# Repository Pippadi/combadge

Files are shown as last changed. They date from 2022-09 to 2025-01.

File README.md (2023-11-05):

# combadge [Work in Progress]

A Star Trek combadge built with the ESP32-S3.

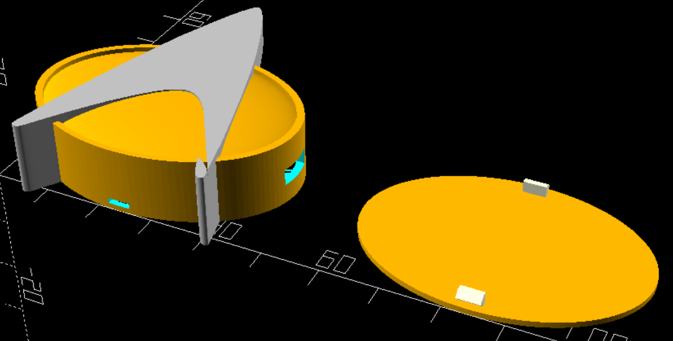
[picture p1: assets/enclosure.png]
Enclosure


> No copyright infringement is intended.
> This is simply a personal endeavor for fun and learning.

## Details

- Hardware and electronics: [hardware/pcb](hardware/pcb)
- Main ESP32 firmware: [software/combadge](software/combadge)
- Audio bridge: [software/bridge](software/bridge)
- 3D-printable enclosure: [hardware/enclosure](hardware/enclosure)
- Nuggets for testing: [software/test](software/test)
- Helpful scripts/tools: [software/tools](software/tools)

This is pretty much the entire directory tree. Happy exploring!

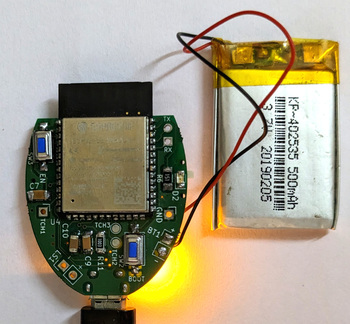
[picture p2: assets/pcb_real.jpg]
Assembled PCB
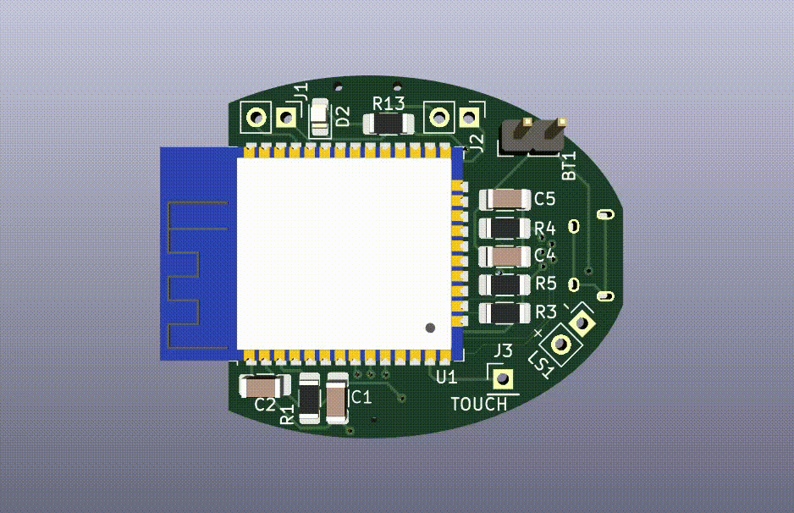
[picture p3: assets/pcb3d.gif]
PCB 3D View
 

## Goals

Hardware has now been verified to work.

Some kind of basic walkie-talkie functionality is in the works, built on top of a custom Combadge Real-time Audio Protocol.
[WebRTC](https://webrtc.org) or [Matrix](https://matrix.org) support is a goal for the distant future.

Ahead of this, the roadmap is largely undecided. Capable hardware leaves great scope for software.

## Motivations

This is a hobby project I am pursuing in order to broaden my knowledge and experience with embedded electronics and programming.
And of course, to end up with a combadge better than the ones they used on TV (I believe those are just molded and painted resin).
Please bear in mind that I am a beginner, especially when it comes to the electronics (remember that before you plug the batteries in).

## Community

Suggestions, tips, and contributions are welcome!
I hope that with some (of your?) time and effort, this combadge can grow to become more useful than a block of resin, while still retaining the charm.

All the tools used for this, as mentioned in the READMEs, are free and open-source. Thank you to those that made this possible!

See also [DansDesigns/ComBadge](https://github.com/DansDesigns/ComBadge), a project with a similar theme and very intriguing prospects.

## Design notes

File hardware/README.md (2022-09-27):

# Electronics and PCB

The combadge is built around an [ESP32-WROOM-32](https://www.espressif.com/en/support/documents/technical-documents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).
It is supposedly not recommended for new designs, but it's among the best supported by Arduino for programming, and it seems to be the only ESP32 variant that is cheaply available in my region.

## Sound

I've chosen to adopt I2S peripherals for this project, as they promise better audio quality than their analog counterparts, while reducing the amount of analog circuitry I have to design.
The [ESP32](https://docs.espressif.com/projects/esp-idf/en/v4.2.3/esp32/api-reference/peripherals/i2s.html) supports two I2S peripherals in hardware.

### Microphone

I've zeroed in on the [CMM-3526D-261-I2S-TR](https://www.cuidevices.com/product/audio/microphones/mems-microphones/cmm-3526d-261-i2s-tr).
I suppose any similar microphone will do the job. The manufacturer has very kindly provided [an official footprint](https://www.cuidevices.com/product/resource/pcbfootprint/cmm-3526d-261-i2s-tr).

### Speaker

With a speaker must come an amplifier. I chose the [NAU8315](https://www.nuvoton.com/export/resource-files/DS_NAU8315_DataSheet_EN_Rev1.7.pdf) because it's a class D amplifier that takes I2S input, and can drive a speaker with pretty much no external circuitry.

As an exercise, I designed the PCB footprint for the NAU8315.

I'm still on the lookout for an actual speaker.

## Power Management

The unit runs on a lithium-polymer battery. Exact model and size unknown as of now. I'm expecting it to be one of the usual 3.7V LiPo cells.
At this stage, though, I'm more concerned with battery management.

All the chosen components of the combadge operate on 3.3V. I was hoping to find an all-in-one charging and voltage-regulating IC, but none seem to exist for these parameters.
For charging, I plan to use an [XC6808A4D28R-G](https://www.torexsemi.com/products/battery-charge-ics/series/?name=xc6808) and a zener diode circuit for over-discharge protection.
I found the super tiny 250mA [NCP160](https://www.onsemi.com/products/power-management/linear-regulators-ldo/ncp160) LDO linear regulator for 3.3V power.

I still need to verify whether 250mA is enough for the entire combadge (it better be; it's running off a battery).
I'm hoping decoupling capacitors will take care of any current spikes the ESP32 and speakers may need.

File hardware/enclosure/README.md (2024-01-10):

# Enclosure

The 3D-printable combadge enclosure for the electronics to sit inside. 3D design is done in [OpenSCAD](https://openscad.org/).

I couldn't find any official combadge dimensions online, so I based my dimensions off of numbers given in this [forum thread](https://www.therpf.com/forums/threads/dimensions-of-star-trek-communicator-badge.266118/).

The PCB is a `45mm x 31mm` ellipse with some parts lopped off where required.
The enclosure's ellipse is `47.5mm x 33.5mm`. Walls are `1mm` thick, with a `0.5mm` room for error around the edge of the cavity for the electronics.

The chevron [SVG](chevron.svg) was traced with Inkscape from a bitmap.

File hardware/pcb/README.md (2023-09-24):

# Electronics and PCB

See the [assets](assets) directory for screenshots of the schematics and PCB.

## Component Choices

The combadge is built around an [ESP32-S3-WROOM-1](https://www.espressif.com/en/support/download/documents/modules?keys=&field_type_tid%5B%5D=838).

I chose it because:

- It has hardware I2S and touch support
- It is well-supported by the Arduino toolchain
- It is cheaply available in my region

### Sound

I've chosen to adopt I2S peripherals for this project, as they promise better audio quality than their analog counterparts, while reducing the amount of analog circuitry I have to design.
The [ESP32-S3](https://docs.espressif.com/projects/esp-idf/en/latest/esp32s3/api-reference/peripherals/i2s.html) supports two I2S peripherals in hardware.

#### Microphone

I've zeroed in on the [Knowles SPH0645LM4H-1](https://www.knowles.com/docs/default-source/default-document-library/sph0645lm4h-1-datasheet.pdf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).
Any similar microphone ought to do the job.

I use the INMP441 for prototyping because it's available as a module. I would have stuck with it for the PCB, but it seems to be discontinued by the manufacturer.

#### Speaker

The [Taoglas SPKM.10.8.A](https://www.taoglas.com/product/10-mm-round-miniature-speaker-500mw/) seems like an adequate speaker for the job.

A [MAX98357AETE+T](https://www.analog.com/en/products/max98357a.html#product-overview) class D amplifier drives the speaker.
It's what I use to prototype.

### Power Management

The unit runs on a lithium-polymer battery. Exact model and size undecided as of now. It will be one of the usual 3.7V LiPo cells.
All the chosen components of the combadge operate on 3.3V. I was hoping to find an all-in-one charging and voltage-regulating IC, but my searches yielded none for these parameters.

Charging is handled by an [MCP73831](https://www.microchip.com/en-us/product/MCP73831).
A 300mA [TLV74333PDBVR](https://www.ti.com/product/TLV743P/part-details/TLV74333PDBVR) LDO linear regulator provides 3.3V power.
A [TLV431AQFTA](https://www.diodes.com/assets/Datasheets/TLV431Q.pdf)-based circuit conditionally disables the regulator for battery over-discharge protection.

## PCB

The PCB has been designed in KiCAD.

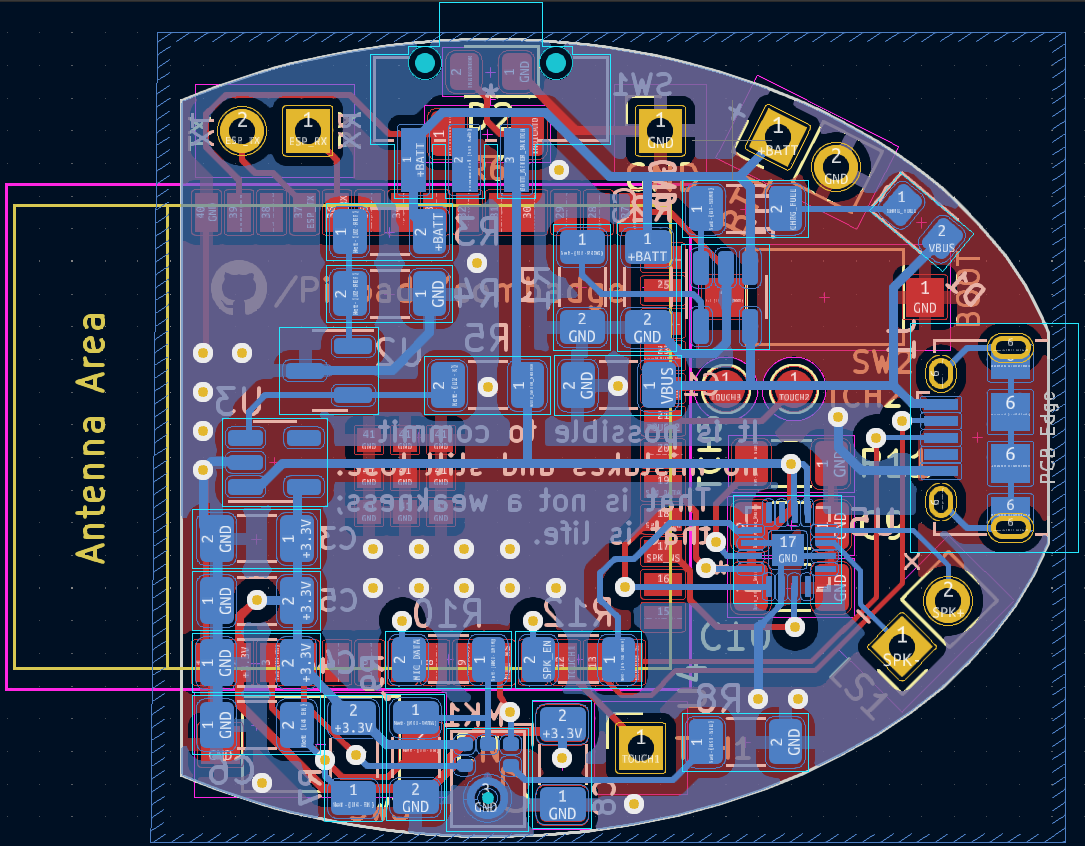
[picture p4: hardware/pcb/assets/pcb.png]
PCB


- Footprints are chosen to be as large as possible where applicable, to facilitate hand-soldering or rework.
- The PCB has headers to which battery and speaker wires can be soldered.
- Certain measurements can be seen in the `User.Comments` layer.

This project makes use of the official Espressif [ESP32 KiCAD libraries](https://github.com/espressif/kicad-libraries).

You will need to change the paths to the third party symbols in the library and footprint managers. I've just plonked everything in a gitignored folder called `third-party`.

## Notes

### Crackling on speaker

When I was prototyping, I was powering everything off my computer's USB port. The INMP441 microphone module worked well, but the MAX98357 with no power supply filtering was horribly noisy.
Some beefy electrolytic capacitors reduced the noise, but did not eliminate it.

The root cause of the noise turned out to be the fact that I was powering the speaker through the AMS1117 3.3V regulator on my ESP32 dev board.
The regulator could not handle the current spikes demanded by the speaker, so its output voltage ended up dropping.
Hooking the speaker up directly to the USB 5V line (VIN on my particular dev board) solved the issue.

The PCB has been designed such that the amplifier is powered directly by the battery.
There are also some large low-transient-response-time ceramic capacitors for any bursts of energy components may need.

### SPH0645LM4H woes

The SPH0645 is known to have some quirks in its I2S interface, to do with the synchronization of the clock and data signals.
In addition, the signal it outputs has a weird offset from 0.

The required workaround for the first problem has been successfully implemented and the second is more of an annoyance.
Nevertheless, a future board revision may be better off with a more standard-compliant microphone like the ICS43434.

### Power stability during battery-less operation

The MCP73831 datasheet specifies a minimum value of 4.7uF for a capacitor across the battery side (C2 here) for stable supply when the battery is disconnected.
This is enough for the ESP32-S3 to boot, but not enough for more current-demanding tasks like turning on WiFi.
Future board revisions should have more and bigger capacitors to avoid brownouts when testing without a battery.

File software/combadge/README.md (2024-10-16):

# combadge

The code for the actual combadge, written in C++ for use with [Arduino](https://www.arduino.cc/), and of course the [ESP32 toolchain](https://github.com/espressif/arduino-esp32).
While the current hardware uses the ESP32-S3, the code aims to retain support for the ESP32.

## Usage

- Edit `config.h` to match your hardware and software configurations.
    + The default pins and peripherals correspond to the hardware in this repository. Change accordingly if using something different.
    + WiFi credentials and bridge host and port will need to be changed per your setup.
    + At present, all involved parties will need to have the same audio configuration. So, changing items such as `sample_t` or `SAMPLE_RATE` will require similar changes to the bridge and the other clients/combadges.
- Run `make SOC="esp32s3"` and `make flash PORT="/dev/<your port>"`. `SOC` can be set to `esp32` if required.

## Dependencies

- [Arduino CLI](https://arduino.github.io/arduino-cli/0.36/) (when building with Makefile)
- WiFi (See [`WiFiClient.h`](https://github.com/espressif/arduino-esp32/blob/master/libraries/WiFi/src/WiFiClient.h))
- I2S (See [`i2s.h`](https://github.com/espressif/arduino-esp32/blob/master/tools/sdk/esp32/include/driver/include/driver/i2s.h) and [`hal/i2s_types.h`](https://github.com/espressif/arduino-esp32/blob/master/tools/sdk/esp32/include/hal/include/hal/i2s_types.h))

## Outline

At startup, two threads are started - one for transmitting microphone data and another for receiving and playing back speaker data.

All data is sent with the Combadge Real-time Audio Protocol (CRAP).

The intricacies of I2S communication are abstracted out to classes, specially defined for each hardware peripheral.
The underlying plan is to eventually define a speaker and microphone interface, and write uniform implementations for specific microphone and speaker peripherals to make switching hardware simpler.

Configurations, constants, and other definitions can be found in [`config.h`](config.h).

## Combadge Real-time Audio Protocol

[CRAP](src/crap.h) is a standard for sending audio data and transmission-related events.

### Topology

A central bridge handles all communication to an from an individual client (badge).
Clients are aware only of the existence of the bridge.
The bridge has the responsibility of routing audio data between clients, and sending the appropriate ephemeral events when necessary.

### Communication

CRAP uses TCP as the underlying communication protocol. A client connects to a bridge on startup, and keeps the connection open.
The client is considered to be offline when the socket is closed.

Information is sent in CRAP packets. A packet mandatorily has a header, and may have a body.
The `PacketHeader` has the following structure.

```c
typedef struct {
    uint32_t type;
    uint32_t size;
} PacketHeader;
```

`type` holds an enumerated intent of the message. `size` holds the size in bytes of the rest of the message body.
Currently, three packet `type`s have been defined.
These three messages are used both by badges and the bridge to start and stop transmissions.

- `AUDIO_START`: Starts an audio transmission. `size` is 0 as no further body is necessary.
- `AUDIO_STOP`: Ends an audio transmission. `size` is 0 as no further body is necessary.
- `AUDIO_DATA`: Holds audio samples in the agreed-upon format (currently raw signed 16-bit little-endian). `size` is the number of samples read times the configured `BYTES_PER_SAMPLE`.

Right now, configurations like sample rate and bitness are hardcoded (but modifiable in `config.h`) for the sake of simplicity.
Allowing on-the-fly setting of such parameters is a goal for the future.
It is currently assumed that both the bridge and clients have been appropriately configured to use the same audio format.

For more information on the bridge, see [/software/bridge](/software/bridge).

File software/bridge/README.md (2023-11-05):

# combridge

A bridge which aggregates and routes audio streams from multiple badges/clients, implementing the [Combadge Real-time Audio Protocol](/software/combadge).

Audio transmissions from clients are aggregated by the bridge such that each client receives a single audio stream to play back.

For now, the aggregated stream for a client is the sample-by-sample sum of the streams from other clients.
In time, streams will be converted to frequency domain and aggregated that way. This makes handling of streams with different sample rates and packet sizes easier.
Acoustic echo cancellation, active noice cancellation, and automatic gain control are also on the list of things to implement.

In its current state, the bridge is very rudimentary, kludgy, and buggy.

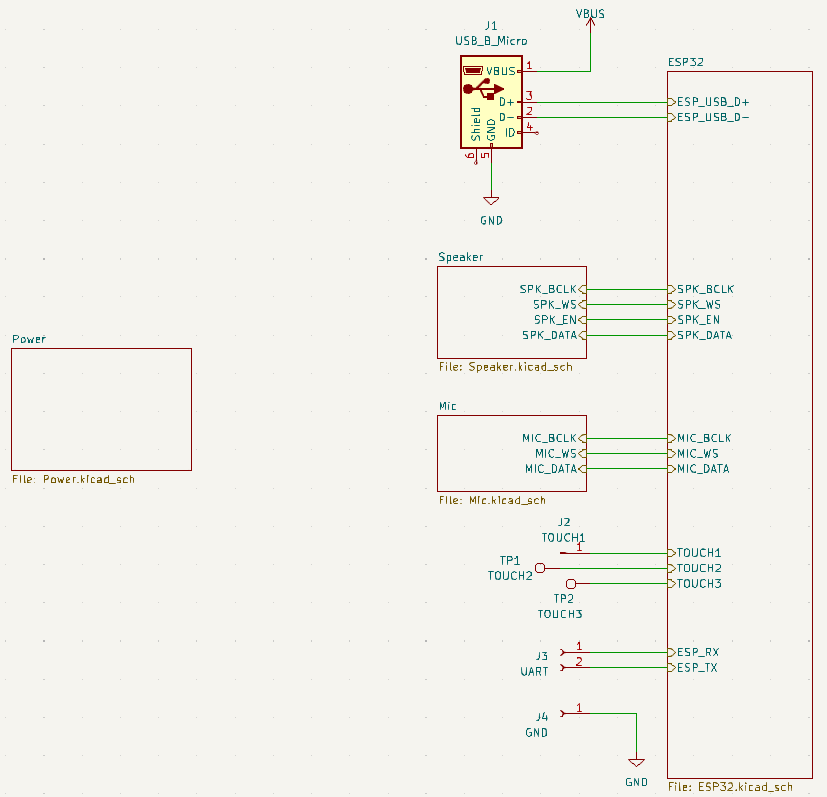
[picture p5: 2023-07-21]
hardware/pcb/assets/TopLevelSchematic.png

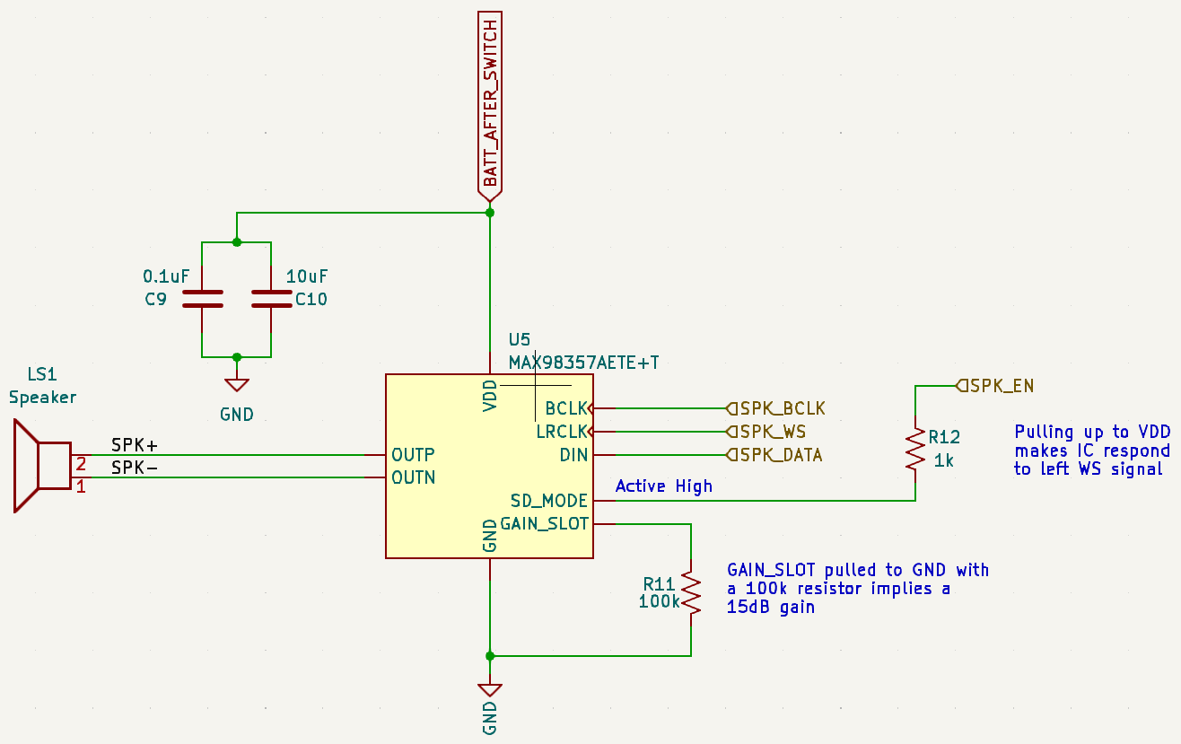
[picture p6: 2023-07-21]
hardware/pcb/assets/SpeakerSchematic.png

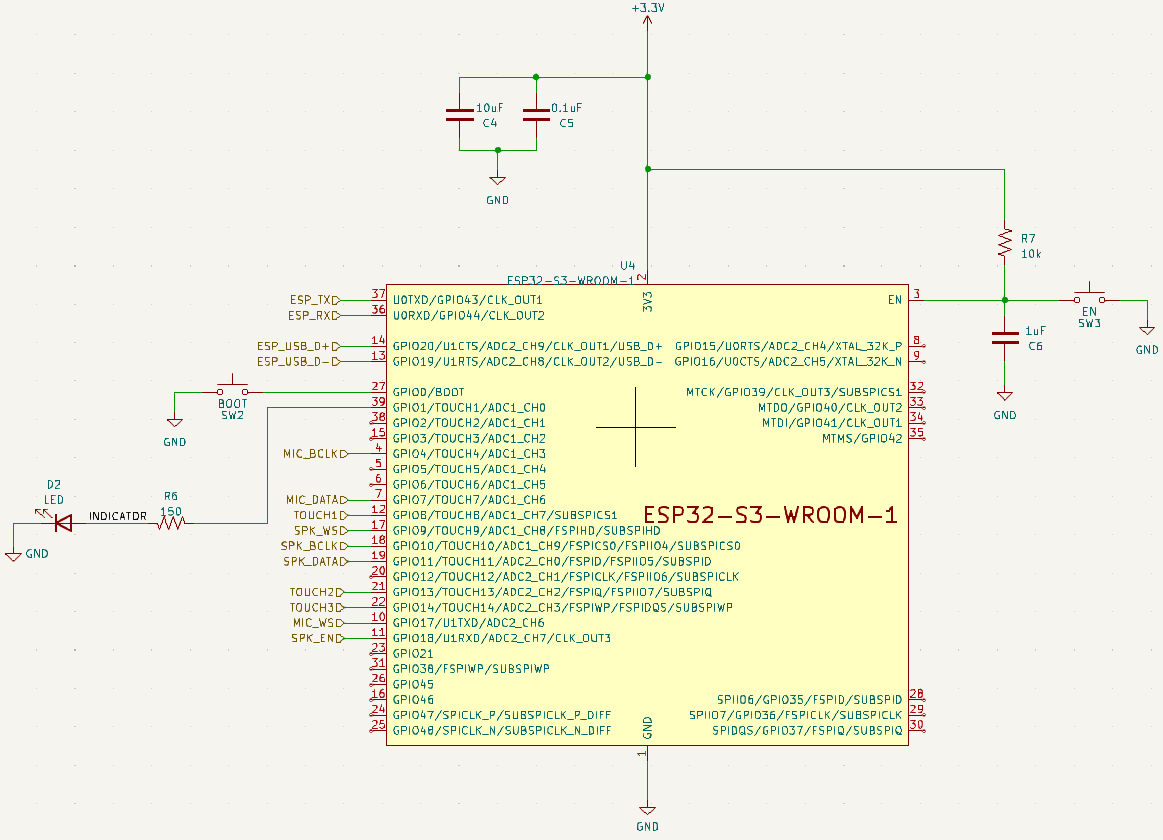
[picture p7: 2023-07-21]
hardware/pcb/assets/ESP32Schematic.png

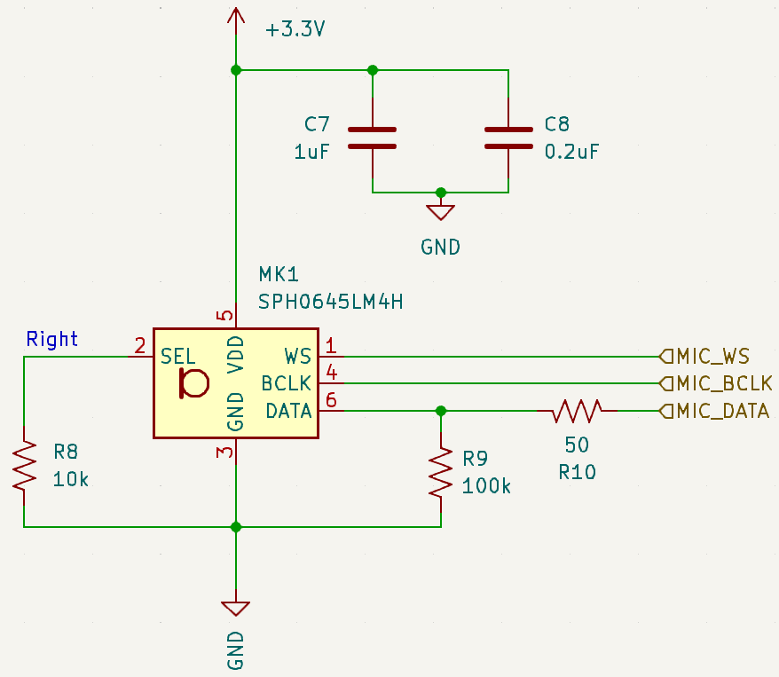
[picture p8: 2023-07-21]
hardware/pcb/assets/MicrophoneSchematic.png

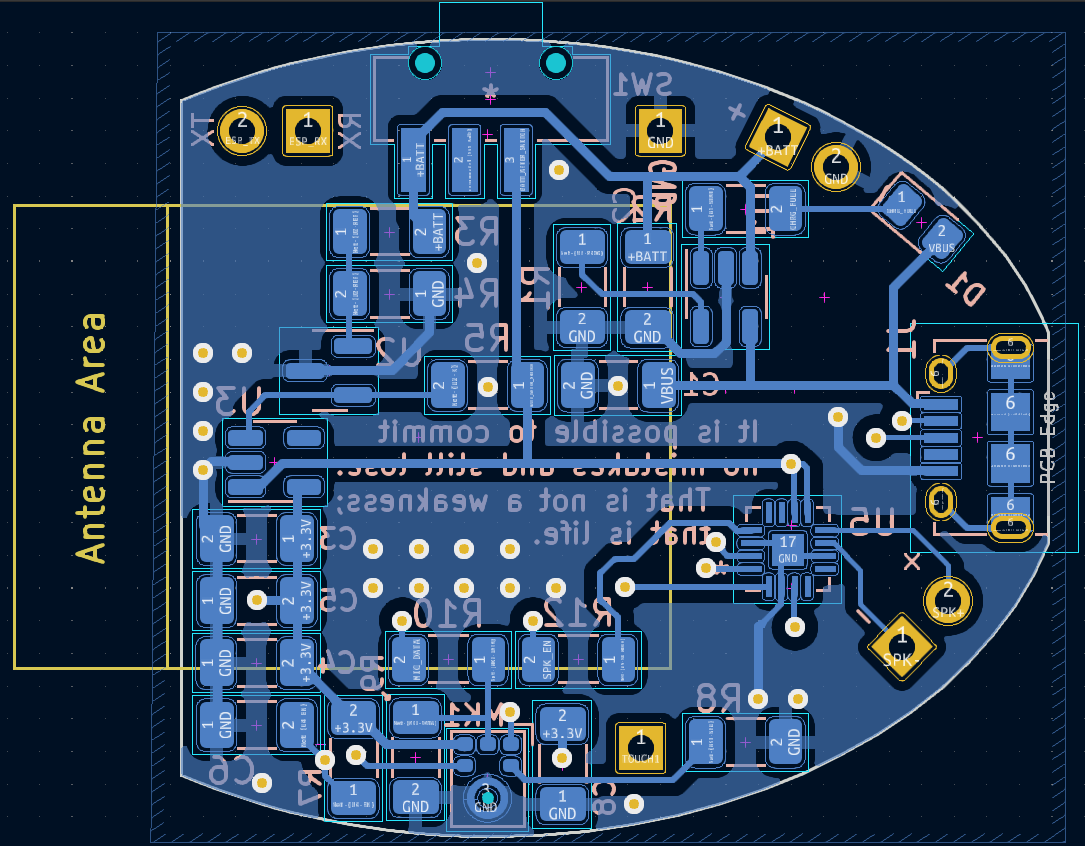
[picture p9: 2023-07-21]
hardware/pcb/assets/PCBRear.png

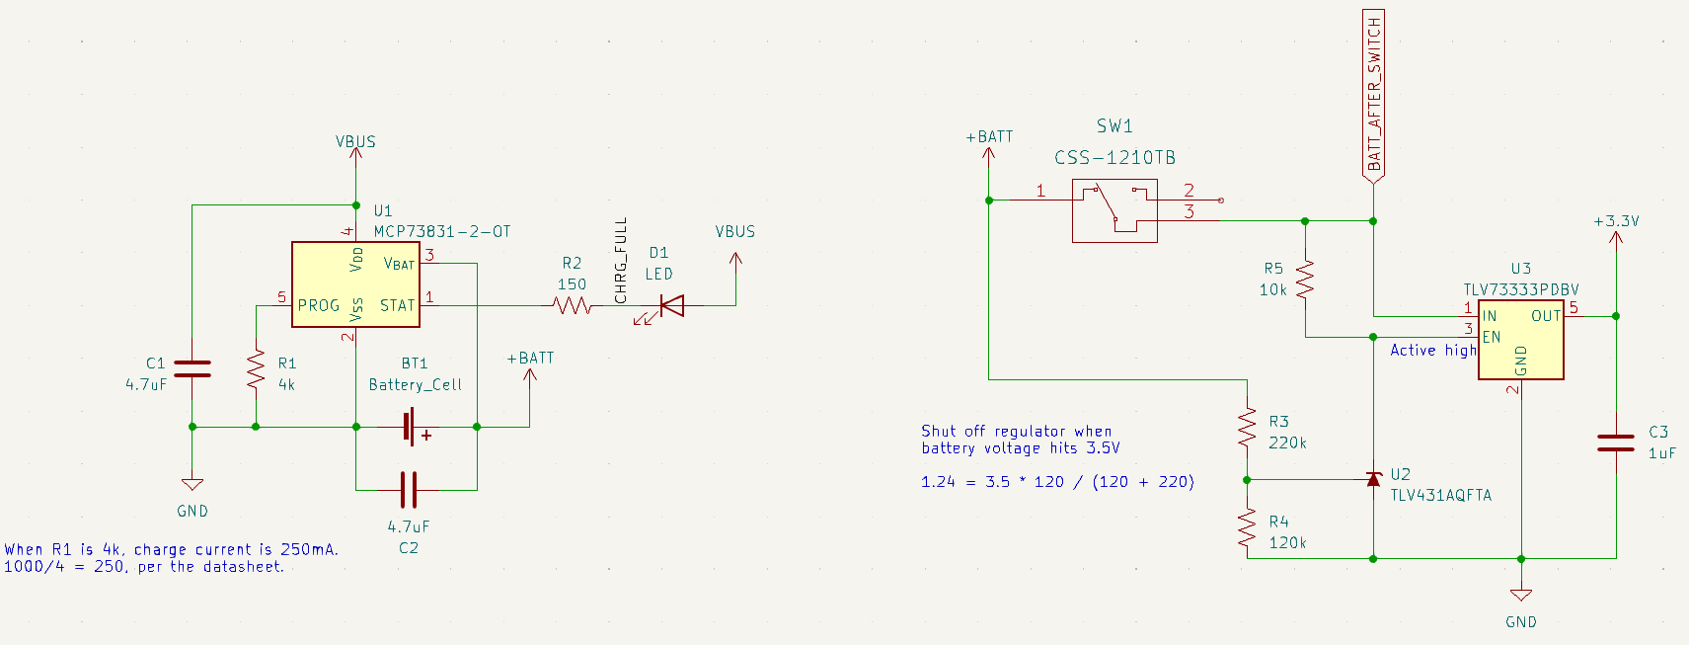
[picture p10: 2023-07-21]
hardware/pcb/assets/PowerManagementSchematic.png

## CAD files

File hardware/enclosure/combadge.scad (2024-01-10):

$wallThickness = 1;
$wiggleRoom = 0.5;
$chamberDepth = 10;

$pcbMajorAxis = 45;
$pcbMinorAxis = 31;

$chevronHeight = 13;

$chamberLength = $pcbMajorAxis + 2*$wiggleRoom;
$chamberWidth = $pcbMinorAxis + 2*$wiggleRoom;
$baseLength = $chamberLength + 2*$wallThickness;
$baseWidth = $chamberWidth + 2*$wallThickness;

$clipWidth = 4;
$clipHeight = 2;

$fn=128;

module scale_width() {
    translate([$baseLength/2, $baseWidth/2, 0])
        scale([$baseLength/$baseWidth, 1, 1])
        children();
}

module chevron() {
    difference() {
        linear_extrude($chevronHeight) import("chevron.svg");
        translate([10, 40, 0]) cube([30, 30, 8]);
    }
}

module annulus(outer_radius, width, height) {
    linear_extrude(height) difference() {
        circle(outer_radius);
        circle(outer_radius - width);
    }
}

module base_top() {
    scale([1, 1, 5.5/$baseWidth])
        rotate_extrude() 
        intersection() {
           circle($baseWidth/2);
           square([$baseWidth, $baseWidth], center=false);
        }
    annulus($baseWidth/2, 1, 1.75);
}

module base() {
    scale_width()
    union() {
        cylinder($chamberDepth, d = $baseWidth);
        translate([0, 0, $chamberDepth]) base_top();
    }
}

module cavity_with_holes() {
    scale_width() cylinder($chamberDepth, d = $chamberWidth);
    translate([$baseLength/2, $baseWidth/2, $chamberDepth/2]) {
        translate([0, $baseWidth/2, 1]) cube([5, 5, 3], center=true);
        translate([$baseLength/2, 0, 0]) cube([5, 7, 3], center=true);
    }
    translate([$baseLength/2, 0, 0.5+$clipHeight/2]) {
        cube([$clipWidth, 5, 1], center=true);
        translate([0, $baseWidth, 0]) cube([$clipWidth, 5, 1], center=true);
    }
}

module combadge() {
    difference() {
        union() {
            color("#c0c0c0") translate([6, -2, 0]) scale([0.85, 0.85, 1]) chevron();
            color("#ffb700") base();
        }
        cavity_with_holes();
    }
}

module triangularPrism(side, depth, center=false) {
    linear_extrude(depth) polygon([[0, 0], [side, 0], [side/2, sqrt(3)*side/2]]);
}

module snapClip(height, width, center) {
    translate(center==true ? [-1, -width/2, 0] : [0, 0, 0])
    union() {
        translate([0, 0, height]) rotate([-90, 0, 0])
        linear_extrude(width)
        polygon([[0, 0], [1 ,0], [2, 1], [1, 1], [1, height], [0, height]]);
    }
}

module back() {
    translate([$baseLength/2, 0, $wallThickness]) union() {
        translate([0, 0.5+$wallThickness, 0]) rotate([0, 0, -90])
        snapClip($clipHeight, $clipWidth, true);
        translate([0, $baseWidth-(0.5+$wallThickness), 0]) rotate([0, 0, 90])
        snapClip($clipHeight, $clipWidth, true);
    }
    scale_width() color("#ffb700")
    cylinder($wallThickness, d=$baseWidth, center=false);
}

combadge();
translate([60, 0, 0])
back();

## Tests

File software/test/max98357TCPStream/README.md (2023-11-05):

# max98357TCPStream

A test for streaming audio data over TCP to the MAX98357.

Set WiFi credentials and I2S configurations as necessary in `max98357TCPStream.ino`.
Configure `streamSound.py` to use the corresponding settings as well.

Next, use `ffmpeg` to convert a given audio file to the required raw format. Change settings if necessary.

```sh
ffmpeg -y -i YourSound.mp3 -f s16le -ac 1 -ar 44100 YourSound.raw
```

Finally, upload the code to the ESP32, and invoke the python script.

```sh
python3 streamSound.py YourSound.raw
```

Audio playback should be fairly smooth. If you have noise, it is very likely to be on the power supply line.
Probing with an oscilloscope may be useful to diagnose issues. See [hardware/pcb](/hardware/pcb#crackling-on-speaker) for more insight.

To make sure it's not your testing scripts that are at fault, use `streamSound.py` in conjunction with [/software/test/inmp441TCPStream/tcpRecorder.py](/software/test/inmp441TCPStream/tcpRecorder.py) to make sure that the sound you put in is the same sound you get out.

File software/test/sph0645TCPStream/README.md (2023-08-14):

# sph0645TCPStream

A test program which streams recording microphone data points over TCP for a Python program to persist to file

## Usage

1. Modify `sph0645TCPStream.ino` to set constants like pins and WiFi credentials commensurate with your setup.
2. Open port 1592 on your firewall, and run `tcpRecorder.py`.
3. Upload the sketch to your ESP32.
4. Let the setup run while making test noises.
5. Terminate the Python program with Ctrl-C.
6. Launch Audacity, and use `File -> Import -> Raw Data` to import your data as 44100Hz signed 16-bit little-endian (should be default).

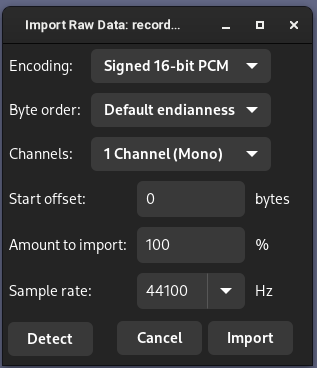
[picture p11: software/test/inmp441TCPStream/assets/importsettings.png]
Audacity import settings


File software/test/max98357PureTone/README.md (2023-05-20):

# MAX98357 Pure Tone test

The ESP32 generates a pure tone and sends it over I2S to the MAX98357.

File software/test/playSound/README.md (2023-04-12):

# playSound

A test to verify whether audio clip playback works with the MAX98357.

The sound clip header file was generated with [tools/soundClips](/software/tools/soundClips).
So far, I've had good results with 44100Hz sample rates for both the audio clip and the amplifier.

16000Hz playback works with the amplifier, but I just can't get a sound clip to play at that sample rate, and I don't know why.
I still need to test other sample rates (and verify that my process isn't at fault) to see where exactly it stops working.

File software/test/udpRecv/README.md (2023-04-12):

# UDP reception test

This is a simple set of programs for testing testing UDP reception.
The python program sends packets with the same content (no PRBS or anything right now {Yes, I just learned what a PRBS was}).
The ESP prints the number of bytes read and the first character in the bytestream.

Yeah, this needs to be improved.

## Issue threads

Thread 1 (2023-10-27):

Great Progress!

DansDesigns, 2023-10-27:
Hi Pippadi,

Loving the progress youve made!
I see you have moved over to the new ESP32 chips.. have you tested the built-in speech recognition functions yet?

Have you considered putting a video together showing the current working state or the Badge?

Keep up the good work!

Pippadi, 2023-11-01:
Thank you!

No, not yet! I was under the impression earlier that I needed a separate DSP chip or something for the speech recognition to work, but some more reading tells me that I don't. Thanks for the reminder!

College and stuff has been keeping me busy lately, so I haven't been able to give this project as much attention as I want to. I'm trying to get some kind of real-time multi-badge audio streaming working with a central bridge. Perhaps that should be my milestone for the first video.

I've been meaning to learn a little bit about audio signal processing, so that I can implement some basic echo and noise cancellation. Again, I haven't found the time, and these don't look like the kind of topics that can be covered in a week or two :)

Pippadi, 2024-03-09:
Enabled the Discussions feature. Closing.

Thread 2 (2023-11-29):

Feature Request: Touch Sensor Input(s)

cinderblock, 2023-11-29:
Awesome work!

I see that the ESP32-S3 has a Touch controller. Have you considered bringing a couple GPIO out that have touch support? Could make for awesome touch buttons!

Pippadi, 2023-11-30:
Thank you!
The current iteration of the hardware does in fact have three touch-capable GPIOs broken out (see [schematic](https://github.com/Pippadi/combadge/blob/main/hardware/pcb/assets/TopLevelSchematic.png)).

`TCH1` is intended to be connected to the chevron and act as the main button. `TCH2` and `TCH3` were admittedly added as afterthoughts, and are just broken out to some test points because I was out of board space :)

At present, the software makes use of only `TCH1`, but I'm sure some use will be found for the other two.

cinderblock, 2023-11-30:
Oh dam! I didn't see a schematic print so I couldn't investigate fully without starting up the full KiCad and was going off of, what may be old, renderings.

Carry on :)

Closed 2023-11-30.

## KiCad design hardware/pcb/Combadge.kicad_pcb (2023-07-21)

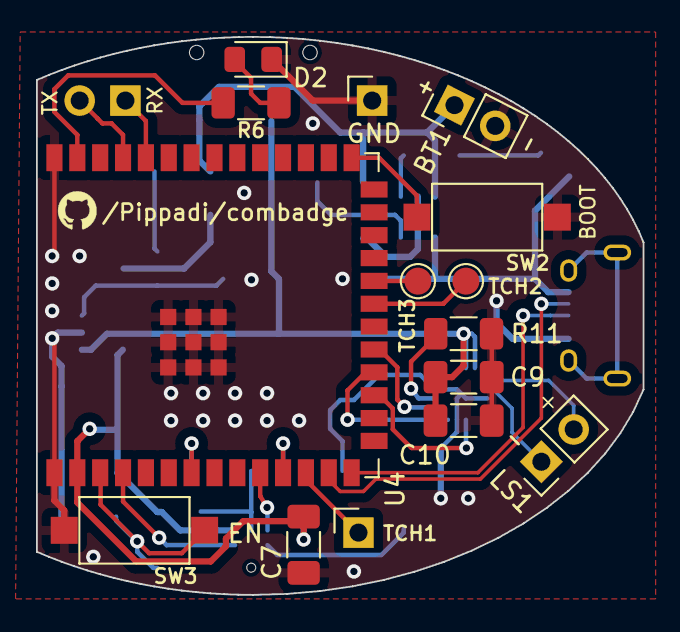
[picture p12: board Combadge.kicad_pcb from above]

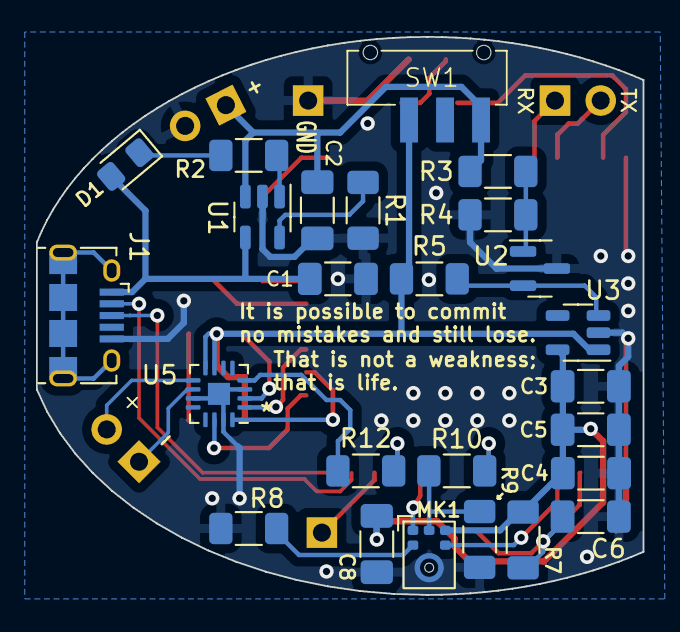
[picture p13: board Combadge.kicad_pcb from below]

Board: 2 copper layers, 33.7 x 31.0 mm, 41 parts (25 on the bottom side), 34 nets.

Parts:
BT1: Battery_Cell; PinHeader_1x02_P2.54mm_Vertical
C1, C2: 4.7uF; C_1206_3216Metric_Pad1.33x1.80mm_HandSolder
C3, C6, C7: 1uF; C_1206_3216Metric_Pad1.33x1.80mm_HandSolder
C4, C10: 10uF; C_1206_3216Metric_Pad1.33x1.80mm_HandSolder
C5, C9: 0.1uF; C_1206_3216Metric_Pad1.33x1.80mm_HandSolder
C8: 0.2uF; C_1206_3216Metric_Pad1.33x1.80mm_HandSolder
D1, D2: LED; LED_0805_2012Metric_Pad1.15x1.40mm_HandSolder
J1: USB_B_Micro; USB_Micro-B_Amphenol_10118194_Horizontal
J2: TOUCH1; PinHeader_1x01_P2.54mm_Vertical
J3: UART; PinHeader_1x02_P2.54mm_Vertical
J4: GND; PinHeader_1x01_P2.54mm_Vertical
LS1: Speaker; PinHeader_1x02_P2.54mm_Vertical
MK1: SPH0645LM4H; Knowles_SPH0645LM4H-6_3.5x2.65mm
R1: 4k; R_1206_3216Metric_Pad1.30x1.75mm_HandSolder
R2, R6: 150; R_1206_3216Metric_Pad1.30x1.75mm_HandSolder
R3: 220k; R_1206_3216Metric_Pad1.30x1.75mm_HandSolder
R4: 120k; R_1206_3216Metric_Pad1.30x1.75mm_HandSolder
R5, R7, R8: 10k; R_1206_3216Metric_Pad1.30x1.75mm_HandSolder
R9, R11: 100k; R_1206_3216Metric_Pad1.30x1.75mm_HandSolder
R10: 50; R_1206_3216Metric_Pad1.30x1.75mm_HandSolder
R12: 1k; R_1206_3216Metric_Pad1.30x1.75mm_HandSolder
SW1: SW_SPDT; CSS-1210TB
SW2: BOOT; SW_SPST_CK_RS282G05A3
SW3: EN; SW_SPST_CK_RS282G05A3
TP1: TOUCH2; TestPoint_Pad_D1.5mm
TP2: TOUCH3; TestPoint_Pad_D1.5mm
U1: MCP73831-2-OT; SOT-23-5
U2: TLV431AQFTA; SOT-23
U3: TLV73333PDBV; SOT-23-5
U4: ESP32-S3-WROOM-1
U5: MAX98357AETE+T; TQFN-16-1EP_3x3mm_P0.5mm_EP1.23x1.23mm

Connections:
+3.3V: C3.1, C4.2, C5.2, C7.2, C8.2, MK1.5 (VDD), R7.2, U3.5 (OUT), U4.2 (3V3)
+BATT: BT1.1 (+), C2.1, R3.2, SW1.3 (C), U1.3 (V_{BAT})
/ESP32/ESP_RX: J3.1, U4.36 (U0RXD/GPIO44/CLK_OUT2)
/ESP32/ESP_TX: J3.2, U4.37 (U0TXD/GPIO43/CLK_OUT1)
/ESP32/ESP_USB_D+: J1.3 (D+), U4.14 (GPIO20/U1CTS/ADC2_CH9/CLK_OUT1/USB_D+)
/ESP32/ESP_USB_D-: J1.2 (D-), U4.13 (GPIO19/U1RTS/ADC2_CH8/CLK_OUT2/USB_D-)
/ESP32/INDICATOR: D2.2 (A), R6.2
/ESP32/MIC_BCLK: MK1.4 (BCLK), U4.4 (GPIO4/TOUCH4/ADC1_CH3)
/ESP32/MIC_DATA: R10.2, U4.7 (GPIO7/TOUCH7/ADC1_CH6)
/ESP32/MIC_WS: MK1.1 (WS), U4.10 (GPIO17/U1TXD/ADC2_CH6)
/ESP32/SPK_BCLK: U4.18 (GPIO10/TOUCH10/ADC1_CH9/FSPICS0/FSPIIO4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), U5.16 (BCLK)
/ESP32/SPK_DATA: U4.19 (GPIO11/TOUCH11/ADC2_CH0/FSPID/FSPIIO5/S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), U5.1 (DIN)
/ESP32/SPK_EN: R12.2, U4.11 (GPIO18/U1RXD/ADC2_CH7/CLK_OUT3)
/ESP32/SPK_WS: U4.17 (GPIO9/TOUCH9/ADC1_CH8/FSPIHD/SUBSPIHD), U5.14 (LRCLK)
/ESP32/TOUCH1: J2.1, U4.12 (GPIO8/TOUCH8/ADC1_CH7/SUBSPICS1)
/ESP32/TOUCH2: TP1.1, U4.21 (GPIO13/TOUCH13/ADC2_CH2/FSPIQ/FSPIIO7/S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)
/ESP32/TOUCH3: TP2.1, U4.22 (GPIO14/TOUCH14/ADC2_CH3/FSPIWP/FSPIDQS/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)
/Power/CHRG_FULL: D1.1 (K), R2.2
/Speaker/SPK+: LS1.2, U5.9 (OUTP)
/Speaker/SPK-: LS1.1, U5.10 (OUTN)
BATT_AFTER_SWITCH: C9.2, C10.2, R5.1, SW1.2 (B), U3.1 (IN), U5.7 (VDD), U5.8 (VDD)
GND: BT1.2 (-), C1.2, C2.2, C3.2, C4.1, C5.1, C6.1, C7.1, C8.1, C9.1, C10.1, D2.1 (K), J1.5 (GND), J4.1, MK1.3 (GND), R1.2, R4.1, R8.2, R9.2, R11.1, SW2.1, SW3.1, U1.2 (V_{SS}), U2.3 (A), U3.2 (GND), U4.1 (GND), U4.40 (GND), U4.41 (GND), U5.3 (GND), U5.11 (GND), U5.15 (GND), U5.17 (Thermal)
unnamed: MK1.6 (DATA), R9.1, R10.1
unnamed: MK1.2 (SEL), R8.1
unnamed: R1.1, U1.5 (PROG)
unnamed: R2.1, U1.1 (STAT)
unnamed: R5.2, U2.2 (K), U3.3 (EN)
unnamed: R3.1, R4.2, U2.1 (REF)
unnamed: C6.2, R7.1, SW3.2, U4.3 (EN)
unnamed: SW2.2, U4.27 (GPIO0/BOOT)
unnamed: R6.1, U4.39 (GPIO1/TOUCH1/ADC1_CH0)
unnamed: R11.2, U5.2 (GAIN_SLOT)
unnamed: R12.1, U5.4 (SD_MODE)
VBUS: C1.1, D1.2 (A), J1.1 (VBUS), U1.4 (V_{DD})

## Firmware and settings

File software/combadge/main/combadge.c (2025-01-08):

#include <stdio.h>
#include "esp_system.h"
#include "esp_wifi.h"
#include "esp_event.h"
#include "esp_log.h"
#include "freertos/event_groups.h"
#include "lwip/sys.h"
#include "lwip/err.h"
#include "config.h"
#include "src/i2scfg.h"
#include "src/crap.h"
#include "sounds/HailBeep.h"
#include "sounds/TNGChirp1.h"
#include "sounds/TNGChirp2.h"
#include "src/max98357.h"

#define TAG "combadge"

#ifdef MIC_SPH0645
#include "src/sph0645.h"
#else
#include "src/inmp441.h"
#endif

#define min(x, y) ((x) < (y) ? (x) : (y))
#define max(x, y) ((x) > (y) ? (x) : (y))

WiFiClient conn;

MAX98357 spk;

#ifdef MIC_SPH0645
SPH0645 mic;
#else
INMP441 mic;
#endif

volatile bool touched = false;

TaskHandle_t streamToSpkHandle;
TaskHandle_t streamFromMicHandle;

EventGroupHandle_t wifiEventGroup;
#define WIFI_CONNECTED_BIT BIT0

void IRAM_ATTR touchISR() {
#ifdef SOC_ESP32
    if (!touched) {
        touched = true;
    }
#else
    touched = touchInterruptGetLastStatus(TOUCH_PIN);
#endif
}

void app_main() {
    setCpuFrequencyMhz(80);
    btStop();

    pinMode(LED, OUTPUT);
    digitalWrite(LED, LOW);

    establishConnection();

    I2SCfg i2sCfg = {
        .sampleRate = SAMPLE_RATE,
        .bitsPerSample = BITS_PER_SAMPLE,
    };

    MicPinCfg micPins = {
        .bclk = MIC_BCLK,
        .ws = MIC_WS,
        .data = MIC_DATA,
    };
    if (!mic.begin(MIC_PORT, i2sCfg, micPins)) {
        ("Failed initializing microphone");
        while (true)
            blinkCycle(100);
    }

    MAX98357PinCfg spkPins = {
        .bclk = SPK_BCLK,
        .ws = SPK_WS,
        .data = SPK_DATA,
        .enable = SPK_EN,
    };
    if (!spk.begin(SPK_PORT, i2sCfg, spkPins)) {
        ESP_LOGE(TAG, "Failed initializing speaker");
        while (true)
            blinkCycle(100);
    }

    playSound(TNGChirp1, TNGChirp1SizeBytes);

    //xTaskCreatePinnedToCore(streamToSpk, "StreamToSpk", 10240, NULL, 0, &streamToSpkHandle, 0);
    xTaskCreatePinnedToCore(streamFromMic, "StreamFromMic", 10240, NULL, 0, &streamFromMicHandle, 1);

    touchAttachInterrupt(TOUCH_PIN, touchISR, TOUCH_THRESHOLD);

    loop();
}

void streamToSpk(void*) {
    static bool receiving = false;
    static uint32_t lastPacketMillis = 0;
    static AudioPacket ad;

    while (true) {
        bool gotBadPacket = false;
        size_t headerBytesRecvd = 0;

        if (conn.available() >= sizeof(PacketHeader))
            headerBytesRecvd = conn.read((uint8_t*) &ad.header, sizeof(PacketHeader));

        if (headerBytesRecvd == sizeof(PacketHeader)) {
            gotBadPacket = false;
            switch (ad.header.type) {
            case AUDIO_START:
                spk.wake();
                ESP_LOGI(TAG, "Starting playback");
                playSound(HailBeep, HailBeepSizeBytes);
                receiving = true;
                break;

            case AUDIO_STOP:
                spk.sleep();
                ESP_LOGI(TAG, "Stopping playback");
                receiving = false;
                break;

            case AUDIO_DATA: {
                size_t totalBytesRead = 0, bytesWritten = 0;
                ad.header.size = min(ad.header.size, BUF_LEN_BYTES);

                while (totalBytesRead < ad.header.size) {
                    size_t bytesRead = conn.read((uint8_t*) ad.data, ((size_t) ad.header.size) - totalBytesRead);
                    totalBytesRead += bytesRead;

                    spk.write((uint8_t*) ad.data, bytesRead, &bytesWritten);
                    if (bytesRead != bytesWritten)
                        ESP_LOGE(TAG, "Wrote only %d of %d bytes to speaker", bytesWritten, bytesRead);
                }
            }
            break;

            default:
                gotBadPacket = true;
            }

            if (gotBadPacket) {
                ESP_LOGE(TAG, "Bad packet type 0x%x with size %d", ad.header.type, ad.header.size);
            } else {
                lastPacketMillis = millis();
                return;
            }
        }

        if (receiving && millis() - lastPacketMillis > TX_DROP_TIMEOUT_MS) {
            ESP_LOGI(TAG, "Transmission dropped");
            receiving = false;
            spk.sleep();
            while (conn.available()) conn.read(); // Clear inbound buffer
        }

        if (!conn.connected()) {
            ESP_LOGI(TAG, "Connection lost");
            receiving = false;
            spk.sleep();
            establishConnection();
        }
    }
}

void streamFromMic(void*) {
    static AudioPacket audio = {};
    audio.header.type = AUDIO_DATA;

    while (true) {
        while (!touched || !conn.connected()) {
            vTaskDelay(10 / portTICK_PERIOD_MS);
        }
        playSound(TNGChirp1, TNGChirp1SizeBytes);
        waitTillTouchReleased();

        ESP_LOGI(TAG, "Starting transmission");
        PacketHeader startMsg = {AUDIO_START, 0};
        conn.write((uint8_t*) &startMsg, sizeof(startMsg));

        while (conn.connected() && !touched) {
            size_t samplesRead = mic.read(audio.data, BUF_LEN_SAMPLES);
            if (samplesRead) {
                audio.header.size = samplesRead * BYTES_PER_SAMPLE;
                conn.write((uint8_t*) &audio, sizeof(audio.header) + audio.header.size);
            }
        }

        ESP_LOGI(TAG, "Ending transmission");
        PacketHeader stopMsg = {AUDIO_STOP, 0};
        conn.write((uint8_t*) &stopMsg, sizeof(stopMsg));
        playSound(TNGChirp2, TNGChirp2SizeBytes);
        waitTillTouchReleased();
    }
}

void playSound(const sample_t* sound, const size_t soundSizeBytes) {
    size_t bytesWritten;
    bool spkAsleep = spk.asleep();
    if (spkAsleep)
        spk.wake();
    spk.write((uint8_t*) sound, soundSizeBytes, &bytesWritten);
    if (spkAsleep)
        spk.sleep();
}

void waitTillTouchReleased() {
    while (touched) {
#ifdef SOC_ESP32
        touched = false;
#endif
        vTaskDelay(100 / portTICK_PERIOD_MS);
    }
}

void initWifi() {
    wifiEventGroup = xEventGroupCreate();

    ESP_ERROR_CHECK(esp_netif_init());
    ESP_ERROR_CHECK(esp_event_loop_create_default());

    esp_netif_create_default_wifi_sta();
    wifi_init_config_t cfg = WIFI_INIT_CONFIG_DEFAULT();
    ESP_ERROR_CHECK(esp_wifi_init(&cfg));

    esp_event_handler_instance_t instance_any_id;
    esp_event_handler_instance_t instance_got_ip;
    ESP_ERROR_CHECK(esp_event_handler_instance_register(WIFI_EVENT,
                    ESP_EVENT_ANY_ID,
                    &wifiEventHandle,
                    NULL,
                    &instance_any_id));
    ESP_ERROR_CHECK(esp_event_handler_instance_register(IP_EVENT,
                    IP_EVENT_STA_GOT_IP,
                    &wifiEventHandle,
                    NULL,
                    &instance_got_ip));

    wifi_config_t wifi_config = {
        .sta = {
            .ssid = WIFI_SSID,
            .password = WIFI_PASSWORD,
            .threshold.authmode = ESP_WIFI_SCAN_AUTH_MODE_THRESHOLD,
            .sae_pwe_h2e = ESP_WIFI_SAE_MODE,
            .sae_h2e_identifier = EXAMPLE_H2E_IDENTIFIER,
        },
    };
    ESP_ERROR_CHECK(esp_wifi_set_mode(WIFI_MODE_STA));
    ESP_ERROR_CHECK(esp_wifi_set_config(WIFI_IF_STA, &wifi_config));
    ESP_ERROR_CHECK(esp_wifi_start());
}

void wifiEventHandle(void* arg, esp_event_base_t event_base, int32_t event_id, void* event_data) {
    if (event_base == WIFI_EVENT && event_id == WIFI_EVENT_STA_START) {
        esp_wifi_connect();
    } else if (event_base == WIFI_EVENT && event_id == WIFI_EVENT_STA_DISCONNECTED) {
        esp_wifi_connect();
    } else if (event_base == IP_EVENT && event_id == IP_EVENT_STA_GOT_IP) {
        ip_event_got_ip_t* event = (ip_event_got_ip_t*) event_data;
        ESP_LOGI(TAG, "got ip:" IPSTR, IP2STR(&event->ip_info.ip));
        xEventGroupSetBits(wifi_event_group, WIFI_CONNECTED_BIT);
    }

    conn.stop();
    while (!conn.connected()) {
        blinkCycle(200);
        conn.connect(BRIDGE, LISTEN_PORT);
    }
    conn.setNoDelay(true);
    ESP_LOGI(TAG, "Connected to %s", BRIDGE);
}

void blinkCycle(int dur_ms) {
    digitalWrite(LED, HIGH);
    vTaskDelay(dur_ms / portTICK_PERIOD_MS);
    digitalWrite(LED, LOW);
    vTaskDelay(dur_ms / portTICK_PERIOD_MS);
}

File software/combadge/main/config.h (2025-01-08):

#include "driver/i2s_std.h"

/* Makefile automatically defines one of these symbols
   when defining SOC="esp32" or SOC="esp32s3" */
//#define SOC_ESP32
//#define SOC_ESP32_S3

#define LED 1

//#define MIC_INMP441
#define MIC_SPH0645

#define MIC_WS GPIO_NUM_17
#define MIC_DATA GPIO_NUM_7
#define MIC_BCLK GPIO_NUM_4
#define MIC_PORT I2S_NUM_0

#define SPK_WS GPIO_NUM_9
#define SPK_DATA GPIO_NUM_11
#define SPK_BCLK GPIO_NUM_10
#define SPK_EN GPIO_NUM_18
#define SPK_PORT I2S_NUM_1

typedef int16_t sample_t;
#define BYTES_PER_SAMPLE sizeof(sample_t)
#define BITS_PER_SAMPLE BYTES_PER_SAMPLE * 8

#define SAMPLE_RATE 44100

#define BUF_LEN_SAMPLES 256
#define BUF_LEN_BYTES BUF_LEN_SAMPLES * BYTES_PER_SAMPLE

#define BUF_FULL_INTERVAL_ms int(float(BUF_LEN_SAMPLES) * 1000.0 / float(SAMPLE_RATE))

#define WIFI_SSID "YourSSID"
#define WIFI_PASSWORD "YourPassword"

#define BRIDGE "192.168.8.100"
#define LISTEN_PORT 1701

#define TOUCH_PIN 8

#ifdef SOC_ESP32
#define TOUCH_THRESHOLD 30
#else
#define TOUCH_THRESHOLD 40000
#endif

// Milliseconds to wait after last recieved packet to assume that
// a transmission has "dropped" (stopped without AUDIO_STOP)
#define TX_DROP_TIMEOUT_MS 5000

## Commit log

2022-09-26 Initial commit for PCB
    [Combadge.kicad_pcb, Combadge.kicad_sch]
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2022-09-27 Add charging IC to schematic
    [Combadge.kicad_sch]
2022-09-27 Add over-discharge protection circuit
    [Combadge.kicad_sch, Power.kicad_sch]
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2022-09-28 Add amplifier to schematic
    [Combadge.kicad_sch, Power.kicad_sch]
2022-09-28 Connect I2S devices to ESP32
    [Combadge.kicad_sch]
2022-09-28 Make ancillary ESP32 connections
    [Combadge.kicad_sch]
2022-09-28 Add schematic titles
    [Combadge.kicad_sch, Power.kicad_sch]
2022-09-28 Assign some footprints. Not done.
    [Combadge.kicad_sch, Power.kicad_sch]
2022-09-29 Add some decoupling capacitors
    [Combadge.kicad_sch]
2022-09-29 Finish footprint assignments (not final)
    [Combadge.kicad_pcb, Combadge.kicad_sch, Power.kicad_sch]
2022-09-29 Add basic PCB outline
    [Combadge.kicad_pcb, Combadge.kicad_sch, Power.kicad_sch]
2022-09-29 Route microphone
    [Combadge.kicad_pcb]
2022-09-29 Move incorrectly placed capacitors around microphone
    [Combadge.kicad_pcb]
2022-09-29 Route speaker and amplifier
    [Combadge.kicad_pcb]
2022-10-01 Finish initial version of PCB
    [Combadge.kicad_pcb, Combadge.kicad_sch, Power.kicad_sch]
2022-10-01 Change ground plane to reduce stray capacitances
    [Combadge.kicad_pcb]
2022-10-07 Add PCB cutout SVG
    [Combadge.kicad_pcb]
2022-10-08 Fix some DRC errors
    [Combadge.kicad_pcb]
2022-10-08 Fix more DRC errors and reconnect broken routes
    [Combadge.kicad_pcb]
2022-10-08 Add labels to pins
    [Combadge.kicad_pcb]
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2022-10-09 Replace Nuvoton amplifier with MAX98357
    [Combadge.kicad_sch]
2022-10-09 Add MAX98357 to PCB
    [Combadge.kicad_pcb, Combadge.kicad_sch]
2022-10-10 Cleanup tracks
    [Combadge.kicad_pcb]
2022-10-10 Fix clearance error with BGA pad route
    [Combadge.kicad_pcb]
2022-10-11 Move silkscreen legends around
    [Combadge.kicad_pcb]
2022-10-11 Fix more DRC errors
    [Combadge.kicad_pcb]
2022-10-13 Redo fill zones
    [Combadge.kicad_pcb]
2022-10-13 Tell DRC to ignore courtyard defects
    [Combadge.kicad_pcb]
2022-10-14 Remove unused custom symbols and footprints
    [Combadge.kicad_pcb]
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2022-11-22 Add power switch and redo overdischarge circuit
    [Combadge.kicad_sch, Power.kicad_sch]
2022-11-28 Rework overdischarge protection
    [Combadge.kicad_sch, Power.kicad_sch]
2022-11-28 Replace transistor network with RN4989 in overdischarge circuit
    [Combadge.kicad_sch, Power.kicad_sch]
2022-11-29 Add power switch and rework header placement
    [Combadge.kicad_pcb, Combadge.kicad_sch, Power.kicad_sch]
2022-11-30 Pretty things up a bit
    [Combadge.kicad_pcb]
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2023-02-04 Revert "Merge commit '233b' into code-dev"
    This reverts commit 61eccbea9441850d184a7fe73d19577349dae08b, reversing
    changes made to f4d8feada8c73089aabe5871204545ee146937a6.
    [combadge.ino, config.h]
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2023-02-11 Flatten edge of PCB where micro USB port sits
    [Combadge.kicad_pcb, Combadge.kicad_sch]
2023-02-11 Reduce number of net classes and trace widths
    [Combadge.kicad_pcb]
2023-02-11 Remove warning about unconnected pad
    [Combadge.kicad_pcb, Power.kicad_sch]
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2023-02-12 Fix USP-6B07 footprint
    [Combadge.kicad_pcb]
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2023-02-13 Get started on enclosure
    [combadge.blend]
2023-02-15 Put chevron in 3D model
    [combadge.blend]
2023-02-17 Start enclosure from scratch.
    Create only main base.
    [combadge.blend]
2023-02-17 Revert "Start enclosure from scratch."
    This reverts commit 32f4118cdb9fcf8692dbca84793f07212d7b7ac6.
    [combadge.blend]
2023-02-17 Start over with enclosure, getting measurements right (I hope)
    [combadge.blend]
2023-02-17 Add rim to base
    [combadge.blend]
2023-02-17 Add curvature to top of base
    [combadge.blend]
2023-02-17 Add chevron
    [combadge.blend]
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2023-03-01 Bump KiCad version to 7
    [Combadge.kicad_pcb, Combadge.kicad_sch, Power.kicad_sch]
2023-03-02 Replace XC6808 with MCP73831 in schematic
    [Combadge.kicad_sch, Power.kicad_sch]
2023-03-02 Add MCP73831 to PCB
    [Combadge.kicad_pcb, Combadge.kicad_sch, Power.kicad_sch]
2023-03-02 Use single resistor for setting amplifier gain
    [Combadge.kicad_pcb, Combadge.kicad_sch, Power.kicad_sch]
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2023-03-03 Remove unused custom symbol and footprint
    Why didn't I do this earlier?
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2023-03-06 Replace zener diode setup with TLV431
    [Combadge.kicad_pcb, Combadge.kicad_sch, Power.kicad_sch]
2023-03-06 Make all resistors 1206 and LEDs 0805
    [Combadge.kicad_pcb, Combadge.kicad_sch, Power.kicad_sch]
2023-03-07 Switch to TLV4333PDBVR LDO regulator
    [Combadge.kicad_pcb, Combadge.kicad_sch, Power.kicad_sch]
2023-03-10 Replace BGA IC with QFN
    [Combadge.kicad_pcb, Combadge.kicad_sch, Power.kicad_sch]
2023-03-10 Update footprints to get rid of DRC error
    [Combadge.kicad_pcb]
2023-03-13 Replace chevron with one closer to the one shown on TV
    [combadge.blend]
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2023-03-19 Add relevant measurements to PCB
    [Combadge.kicad_pcb]
2023-03-20 Add ESP32 boot button
    [Combadge.kicad_pcb, Combadge.kicad_sch, Power.kicad_sch]
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2023-04-10 Rework INMP441 read function
    [combadge.ino]
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2023-04-11 Return correct number of samples recorded
2023-04-16 Rewire power switch so that the unit can be turned on
    Thank you to Reddit user justadiode.
    [Combadge.kicad_pcb, Power.kicad_sch]
2023-04-20 Remove acute angles from PCB copper layers
    [Combadge.kicad_pcb]
2023-04-24 Cleanup schematic to follow convention
    Thanks to Reddit users Crazy_Direction_1084 and AgentiMi for introducing
    me to this.
    [Combadge.kicad_sch, ESP32.kicad_sch, Mic.kicad_sch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]
2023-04-24 Update PCB from updated schematic
    [Combadge.kicad_pcb, Combadge.kicad_sch, ESP32.kicad_sch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]
2023-04-24 Replace third party MAX98357 symbol with custom one
    [Combadge.kicad_pcb, Power.kicad_sch, Speaker.kicad_sch]
2023-04-26 Add ground pours
    Thanks to Reddit user AgentiMi for the recommendation
    [Combadge.kicad_pcb]
2023-04-26 Break out ESP enable pin
    [Combadge.kicad_pcb, Combadge.kicad_sch, ESP32.kicad_sch]
2023-04-26 Replace stand-in symbol with custom one for TLV431
    [Combadge.kicad_pcb, Power.kicad_sch]
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2023-05-07 Replace ESP32 with ESP32-S3
    [Combadge.kicad_pcb, Combadge.kicad_sch, ESP32.kicad_sch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]
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2023-05-18 Revert "Add test for streaming audio data over TCP to MAX98357"
    This reverts commit d88ba64b8451a7f6b7af6247099f9c6e46fe6a44.
    [max98357TCPStream.ino]
2023-05-20 Power speaker amplifier directly from battery
    Also increase power trace widths
    [Combadge.kicad_pcb, ESP32.kicad_sch, Power.kicad_sch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]
2023-05-20 Update documentation on speaker noise reduction
    [max98357PureTone.ino]
2023-05-21 Ensure a single touch doesn't register twice
    [combadge.ino]
2023-05-24 Make copper pour cover entire surface of board
    [Combadge.kicad_pcb]
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2023-06-17 Replace EOL CUI devices microphone with Knowles SPH0645
    [Combadge.kicad_pcb, Combadge.kicad_sch, Mic.kicad_sch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]
2023-06-26 Get started on OpenSCAD-based 3D model
    [combadge.scad]
2023-06-26 Add extra touch pads
    [Combadge.kicad_pcb, Combadge.kicad_sch, ESP32.kicad_sch]
2023-06-29 Link to project GitHub on silkscreen
    [Combadge.kicad_pcb]
2023-06-29 Fix badly positioned pin in MAX98357 symbol
    [Speaker.kicad_sch]
2023-06-30 Exclude unpopulated connectors from BOM
    [Combadge.kicad_sch, Speaker.kicad_sch]
2023-06-30 Use noncritical GPIO pins for I2S peripherals
    [Combadge.kicad_pcb, ESP32.kicad_sch]
2023-06-30 Rewire charge indicator LED
    [Combadge.kicad_pcb, Power.kicad_sch]
2023-06-30 Increase track clearance
    [Combadge.kicad_pcb]
2023-07-01 Fix silkscreen snafu
    [Combadge.kicad_pcb]
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2023-07-11 Replace third-party switch footprint with custom
    [Combadge.kicad_pcb, Power.kicad_sch]
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2023-07-24 Get actor-based bridge to a non-crashing (but nonfunctional) state
    [combadge.ino]
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2023-11-12 Avoid reading buffered values beyond sent size
    [combadge.ino]
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2023-12-23 Add textured top to base
    [combadge.scad]
2023-12-24 Rework base and cavity
    [combadge.scad]
2023-12-24 Fix cavity
    [combadge.scad]
2023-12-26 Make space for power switch
    [combadge.scad]
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2023-12-31 Add snap clips to backplate
    [combadge.scad]
2024-01-01 Add slots for snap clips
    [combadge.scad]
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2024-12-08 Begin migration to ESP-IDF
    Untested. Almost certainly doesn't work.
    [combadge.c, max98357.cpp]
